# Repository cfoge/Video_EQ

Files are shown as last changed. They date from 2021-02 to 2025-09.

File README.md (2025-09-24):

# Video Equations Video Synthisizer 

This repo is a source for hardware, firmware and programming of the *Video Equations* video synth by CFOGE

[VIDEO OF THE SYNTH IN ACTION](https://youtu.be/mjo5Ck8bLms?si=FF00txjyV0ThEeUl)

## currently for sale on ETSY [here](https://www.etsy.com/au/listing/1103194946/video-equations-video-synthesizer-pcb)
*NOTE IF YOU BUY A KIT OR PCB FROM ME YOU DO NOT NEED TO PROGRAM THE ANYTHING! THE ROM CHIPS COME PROGRAMED!

It also contains the BOM for the original Standalone version.
and a *build guide* [here](https://docs.google.com/document/d/1xhPcSpx6gMqP5NIOa-hU4GBMXX1HIhc-GGcmYRfW-Dc/edit?usp=sharing)

And a mouser basket for the parts [HERE](https://au.mouser.com/ProjectManager/ProjectDetail.aspx?AccessID=cdce1e85b3)  
If any parts are out of stock, check this basket: [HERE](https://au.mouser.com/ProjectManager/ProjectDetail.aspx?AccessID=809015eedc)

When building be sure to look at the interactive BOM (it is the HTML file above)

3D-printed case files can be found here:
[3d printed cases](https://www.thingiverse.com/thing:4983079)

-- To date there have been 100's of these made by all kinds of amazing people and i am flattered to have seen so manny photos and videos of these in use. They are featured in the collections of so many creative people and institutes such as the New York Film School and Princton Media Lab. The Video Equations is also listed on the Wikipedia page for [Video Synthisizers](https://en.wikipedia.org/wiki/Video_synthesizer#cite_note-14)

If you find this useful and would like to pay it forward you can do so [HERE](https://www.paypal.com/donate?hosted_button_id=XGRSY3M6V94R4)

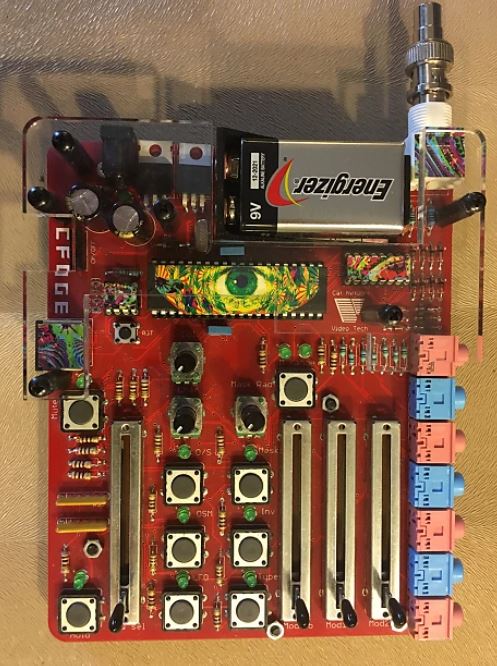
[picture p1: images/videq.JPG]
Red Video Equations


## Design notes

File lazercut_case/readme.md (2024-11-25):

lazer cut case files and pictures of what a Video Equations with a lazer cut case looks like. Instructions linke din the build guide.

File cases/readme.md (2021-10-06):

Cases For the Video Equations as 3d printible STLs

[ALSO ON THINGYVERSE]https://www.thingiverse.com/thing:4983079

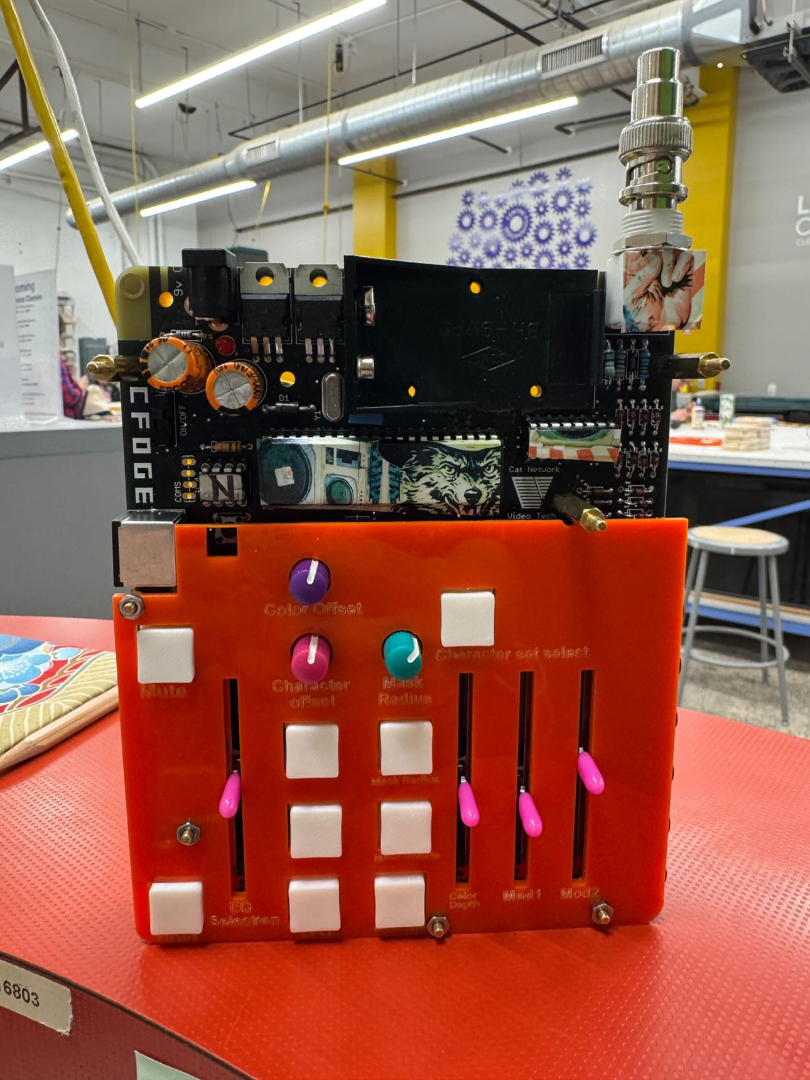
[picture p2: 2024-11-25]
lazercut_case/30529C8E-C561-428F-A3B5-9482B5F51982.JPG

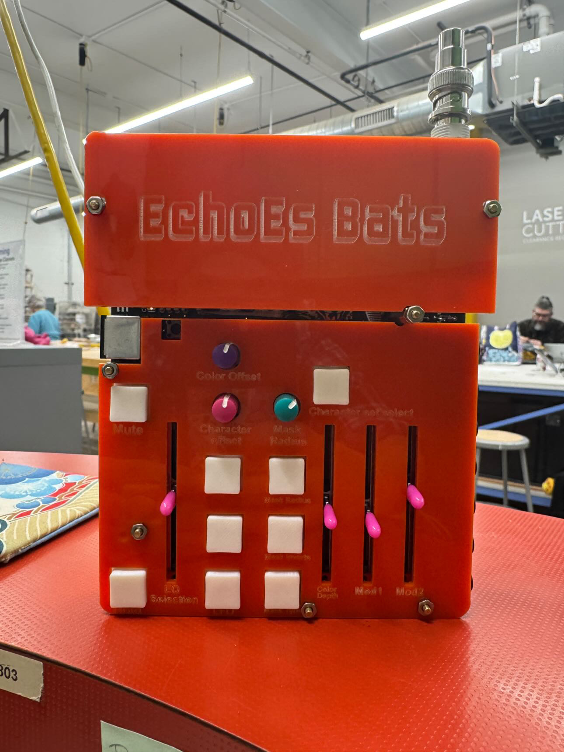
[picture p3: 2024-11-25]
lazercut_case/135A8F83-172F-4E90-950E-6DF78F7B65DF.JPG

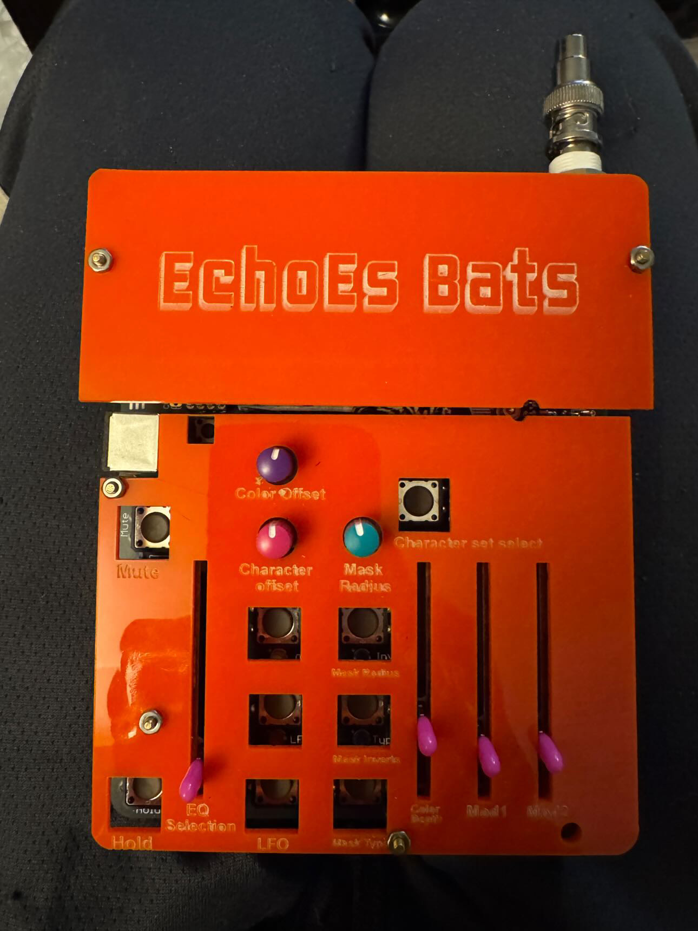
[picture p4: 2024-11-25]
lazercut_case/34D93253-267E-47DA-A76D-7D9487207A3B.JPG

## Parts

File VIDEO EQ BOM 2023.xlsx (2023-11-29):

Customer Reference | VALUE | QTY | NEWARK PART # | PRICE | EXTENDED | DIGIKEY PART # | PRICE | EXTENDED | MOUSER PART # | PRICE | EXTENDED | INFO | ORIGNAL LINK
9v | 2.1mm DC plug (power in is cent -) | 1 | -- |  | $0.00 | EJ508A-ND | $1.28 | $1.28 | -- |  | $0.00 |  | http://www.digikey.com/product-detail/en/mpd-memory-protection-devices/EJ508A/EJ508A-ND/2439547
BAT1 | 9v Battery holder | 1 | -- |  | $0.00 | BH9V-PC-ND | $2.04 | $2.04 | -- |  | $0.00 | Make sure that the positive terminal is on right when looking down with the terminals at the top | http://www.digikey.com/product-detail/en/mpd-memory-protection-devices/BH9VPC/BH9V-PC-ND/31510
C1,C2 | 1000uf Electrolitic Cap | 2 | 74R3415 | $0.00 | $0.00 | P14398-ND | $0.72 | $1.44 | 667-EEU-FM1C102 | $0.00 | $0.00 |  | http://www.digikey.com/product-detail/en/panasonic-electronic-components/EEU-FM1C102/P12366-ND/613727
 | 1000uf Electrolitic Cap (ALT) | 0 | -- |  |  | P12366-ND |  |  | --
C3, C4, C5 | 0.1uf | 3 | 44AC2694 | $0.00 | $0.00 | 495-1149-ND | $0.46 | $1.38 | 871-B32529C1104J | $0.00 | $0.00 |  | http://www.digikey.com/product-detail/en/epcos-tdk/B32529C1104J/495-1147-ND/592724
 | 1000uf Electrolitic Cap(ALT) | 0 | -- |  | $0.00 | 495-1147-ND |  |  | -- |  | $0.00
Coms | 1X4 pinheader | 1 | 63W5458 | $0.00 | $0.00 | 929400E-01-04-ND | $0.47 | $0.47 | 517-929400-01-04-RK | $0.00 | $0.00 |  | http://www.digikey.com/product-detail/en/3m/929400-01-04-RK/929400E-01-04-ND/1093537
D1 | 1n4007 | 1 | 42K2831 | $0.00 | $0.00 | 1N4007GOS-ND | $0.23 | $0.23 | 625-1N4007E-E3/53 | $0.00 | $0.00 | alternate digikey part | http://www.digikey.com/product-detail/en/fairchild-semiconductor/1N4007/1N4007FSCT-ND/965481
D1 (ALT) | 1n4007 | 0 | -- |  | $0.00 | 1N4007FSCT-ND |  |  | -- |  | $0.00 | this digikey part not available
Expand | mini 6pin din | 1 | -- |  | $0.00 | CP-2260-ND | $2.18 | $2.18 | 490-MD-60SM | $0.00 | $0.00 |  | http://www.digikey.com/product-detail/en/cui-inc/MD-60SM/CP-2260-ND/96940
J1-J7 | 3.5mm audio jack (GREEN) | 0 | -- |  | $0.00 | 102-4994-ND | $0.97 | $0.00 | 490-SJ1-3555NG-GR | $0.00 | $0.00 | replacement digikey part | http://www.digikey.com/product-detail/en/cui-inc/SJ1-3555NG/CP1-3555NG-ND/738708
J1-J7 (ALT) | 3.5mm audio jack (BLK OOS) | 0 | -- |  | $0.00 | CP1-3555NG-ND | $0.97 | $0.00 | 490-SJ1-3555NG | $0.00 | $0.00 | digi NON STOCK IN USA | http://www.digikey.com/product-detail/en/cui-inc/SJ1-3555NG-GR/CP1-3555NG-GR-ND/2295996
 | 3.5mm audio jack (BLUE) | 7 | -- |  | $0.00 | 102-4993-ND | $0.97 | $6.79 | 490-SJ1-3555NG-BE | $0.00 | $0.00
R34-R35 | 10K Bussed 6pin | 2 | 62J2820 | $0.00 | $0.00 | 4306R-1-103LF-ND |  | $0.00 | 652-4606X-1LF-10K | $0.00 | $0.00 |  | http://www.digikey.com/product-detail/en/bourns-inc/4606X-101-103LF/4606X-1-103LF-ND/1088960
 |  |  |  |  |  | 4606X-1-103LF-ND
RST | Tactile Switch mom | 1 | 19C7994 | $0.00 | $0.00 | 679-2428-ND | $0.10 | $0.10 | 642-MJTP1230 | $0.00 | $0.00 |  | http://www.digikey.com/product-detail/en/apem-inc/MJTP1230/679-2428-ND/1798037
R1-R3 | 10k pot | 3 | 17M1603 | $0.00 | $0.00 | PTV09A-4020U-B103-ND | $0.83 | $2.49 | 652-PTV09A-4020UB103 (https://www.mouser.com/QuickViewProdDetail.aspx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) | $0.00 | $0.00 | vertical | http://www.digikey.com/product-detail/en/bourns-inc/PTV09A-4020U-B103/PTV09A-4020U-B103-ND/3781130
S1-S9 | 12mm push button mom | 9 | 32AC2270 | out of stock |  | CKN9100-ND | $0.39 | $3.51 | 611-PTS125SM43-LFS | $0.00 | $0.00 |  | http://www.digikey.com/product-detail/en/c-k-components/PTS125SM43-2-LFS/CKN9100-ND/1146743
U1, U3 | 7805 5V req | 1 | 45J1443 | $0.00 | $0.00 | MC7805BTGOS-ND | $0.62 | $0.62 | 926-LM7805CT/NOPB (https://www.mouser.com/QuickViewProdDetail.aspx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) | $0.00 | $0.00 | alternate digikey replacement | http://www.digikey.com/product-detail/en/fairchild-semiconductor/LM7805CT/LM7805CT-ND/458698
U1, U3 (ALT) | 7805 5V req | 0 | -- |  | $0.00 | LM7805CT-ND |  |  | -- |  | $0.00 | TO220 package - out of stock @ digi 3.10.21 (obsolete)
U2 | LM3940 3.3v Reg | 1 | 31AH1990 | $0.00 | $0.00 | LM3940IT-3.3/NOPB-ND | $1.93 | $1.93 | 926-LM3940IT-3.3NOPB (https://www.mouser.com/QuickViewProdDetail.aspx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) | $0.00 | $0.00 | TO220 package | http://www.digikey.com/product-detail/en/texas-instruments/LM3940IT-3.3-NOPB/LM3940IT-3.3-NOPB-ND/308006
Y1 | 5mhz 18pf crystal | 1 | 75Y2315 | $0.00 | $0.00 | 300-6009-ND | $0.54 | $0.54 | 520-50-18-4XEN | $0.00 | $0.00 | possible mouser replacement 5mhf 18pf crystal | http://www.digikey.com/product-detail/en/citizen-finedevice-co-ltd/HC-49-U-S5000000ABJB/300-6009-ND/284197
Y1-A | 5mhz 18pf crystal | 0 | -- |  |  | -- |  |  | 695-HC49US-5-U | $0.00 |  | very long lead for this part from mouser
D2-D15 | 5v zener diode | 14 | 90R9455 | $0.00 | $0.00 | 1N5231B-ND | $0.15 | $2.07 | 512-1N5231B | $0.00 | $0.00 |  | ZENER (http://www.newark.com/nxp/bzx79-c5v1-113/zener-diode-500mw-5-1v-do-35/dp/75R5151) | ZENER AL (https://www.newark.com/multicomp-pro/1n5231b/zener-diode-500mw-5-1v-do-35/dp/90R9455)
SCK - X1 | 16p DIL (DIP) sockt | 1 | 82K7788 | $0.00 | $0.00 | 609-4713-ND | $0.37 | $0.37 | 649-DILB16P-223TLF | $0.00 | $0.00 |  | DIP8 (http://www.newark.com/amphenol-fci/dilb8p-223tlf/dip-socket-8-position-2-54mm-through/dp/53K0893)
SCK - U$2 | 40p DIL (DIP) sockt | 1 | 53K0892 | $0.00 | $0.00 | 609-4716-ND | $0.76 | $0.76 | 649-DILB40P223TLF | $0.00 | $0.00 |  | DIP40 (http://www.newark.com/amphenol-fci/dilb40p-223tlf/dip-socket-40-position-through/dp/53K0892)
SCK - IC1 | 8pin DIL (DIP) socket | 1 | 53K0893 | $0.00 | $0.00 | 609-4717-ND | $0.20 | $0.20 | 649-DILB8P223TLF | $0.00 | $0.00 |  | DIP16 (http://www.newark.com/multicomp/spc15498/dip-socket-16-position-through/dp/82K7788)
VR1-VR4 | 10k slide pot | 4 | 05R8045 | $0.00 | $0.00 | PTA4543-2015DPB103-ND | $1.50 | $6.00 | 652-PTA45432015DPB10 | $0.00 | $0.00 | Timeslide60 | TIMESLIDE60 (http://www.newark.com/bourns/pta4543-2015dpb103/potentiometer-slide-10kohm-250mw/dp/05R8045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)
U$1 | BNC Conector | 1 | 98K4758 | $0.00 | $0.00 | A97552-ND | $2.42 | $2.42 | 571-1-1337542-0 | $0.00 | $0.00 |  | BNC (http://www.newark.com/te-connectivity-greenpar/1-1337542-0/rf-coaxial-bnc-jack-r-a-50-ohm/dp/78M7204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)
LED 1-LED11 | 3mm LED - GREEN | 8 | 97K4040 | $0.00 | $0.00 | 160-1712-ND | $0.36 | $2.88 | 859-LTL-4231 | $0.00 | $0.12 | I use red for the 3 most left led's , red and green will look nice orenge is often too bright. | GREEN (http://www.newark.com/led-technology/l02r3000f1/led-green-t-1-3mm-3-7mcd-567nm/dp/97K4040?ost=1208845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) | RED (http://www.newark.com/led-technology/l4rr3000f1/led-red-t-1-3mm-4-3mcd-635nm/dp/97K4135?ost=1208848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)
LED 1-LED11 | 3mm LED - RED | 3 | 97K4135 | $0.00 | $0.00 | 160-1955-ND | $0.36 | $1.08 | 859-LTL-4211 | $0.00 | $0.00
LED 1-LED11 | 3mm LED - YELLOW | 0 | 97K4047 |  | $0.00 | 160-1961-ND | $0.36 | $0.00 | 859-LTL-4251 | $0.00 | $0.00
LED 1-LED11 | 3mm LED - ORANGE | 0 | 14N9382 |  | $0.00 |  |  |  | 859-LTL-1CHAE | $0.00 | $0.00
on/Off | Slide Switch | 1 | EG1218 |  | $0.00 | EG1903-ND | $0.66 | $0.66 | 612-EG1218 | $0.00 | $0.00 | Switch | SLIDE (http://www.newark.com/e-switch/eg1218/slide-switch-spdt-200ma/dp/15N7301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)
R1-R20 | 100ohm res 1/4w CF | 20 | 38K0326 |  | $0.00 | 100QBK-ND | $0.10 | $2.00 | 603-CFR-25JB-52-100R | $0.00 | $0.00 |  | 100-ohm (http://www.newark.com/multicomp/mcf-0-25w-100r/carbon-film-resistor-100-ohm-250mw/dp/38K0326)
R21 | 1k res 1/4w CC | 1 | 25M8365 |  | $0.00 | RC14JT1K00CT-ND | $0.54 | $0.54 | 791-RC1/4-102JB | $0.00 | $0.00 | sub'd - | 1k 250mw (https://www.newark.com/multicomp-pro/mcf-0-25w-1k/carbon-film-resistor-1kohm-250mw/dp/38K0327?ost=38k0327)
R21 (ALT) | 1k res 1/4w CC | 0 | 72K6178 |  | $0.00 | -- |  |  |  |  |  | -2 dllars and back ordered | 1k (http://www.newark.com/multicomp/mcrc1-4g102jt-rh/carbon-resistor-1kohm-250mw-5/dp/72K6178?ost=1144061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)
R26-R29 & R36-R38 | 47ohm 1/4w CF | 7 | 38K0374 |  | $0.00 | 47QBK-ND | $0.10 | $0.70 | 603-CFR-25JB-52-47R | $0.00 | $0.00 |  | 47-ohm (http://www.newark.com/multicomp/mcf-0-25w-47r/carbon-film-resistor-47-ohm-250mw/dp/38K0374?ost=9339523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)
R30 | 1.1k 1/4w MF | 1 | 59K8658 |  | $0.00 | CMF1.10KQFCT-ND | $0.61 | $0.61 | 71-CMF501K1000FHEB | $0.00 | $0.00 |  | 1.1k (http://www.newark.com/multicomp/mcmf0w4ff1101a50/metal-film-resistor-1-1kohm-250mw/dp/59K8658)
R31 | 270ohm 1/4w MF | 1 | 58K3836 |  | $0.00 | 270ADCT-ND | $0.70 | $0.70 | 603-MFP-25BRD52-270R | $0.00 | $0.00 |  | 270ohm (http://www.newark.com/multicomp/mcmf0w4ff2700a50/metal-film-resistor-270-ohm-250mw/dp/58K3836)
R32 | 500ohm 1/4w MF | 1 | 97M6276 |  | $0.00 | RN60C5000BB14-ND | $0.73 | $0.73 | 71-RN60C5000B | $0.00 | $0.00 |  | 500ohm (http://www.newark.com/multicomp/mcmfr0w4bb5000a50/metal-film-resistor-500-ohm-250mw/dp/97M6276?ost=2396013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)
R33 | 10K 1/4w CC | 1 | 72K6179 |  | $0.00 | RC14JT10K0CT-ND | $0.54 | $0.54 | 791-RC1/4-103JB | $0.00 | $0.00 |  | 10k (http://www.newark.com/multicomp/mcrc1-4g103jt-rh/carbon-resistor-10kohm-250mw-5/dp/72K6179?ost=1133371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)
IC1 | Eprom 24LC256 | 1 |  |  |  |  |  |  |  |  |  | firmware chip, comes with pcb order
U$2 | Paralax P8X32A-D40 | 1 | 11X5686 |  | $7.99 | P8X32A-D40-ND | $9.19 | $9.19 | 619-P8X32A-D40 | $7.99 | $7.99 | Propellor IC | EPROM (https://www.parallax.com/product/602-00013)
X1 | MPC3208 | 1 | 58K1815 |  | $4.40 | MCP3208-CI/P-ND | $3.83 | $3.83 | 579-MCP3208CIP | $3.83 | $3.83 | 8ch ADC | PROPELLER (https://www.parallax.com/product/p8x32a-d40)
 |  |  |  |  |  |  |  |  |  |  | $0.00
 |  |  |  |  |  |  |  |  |  |  | $0.00 |  | ADC (http://www.mouser.com/ProductDetail/Microchip-Technology/MCP3208-CI-P/?qs=9y3LFqDLL8IuAGJEebQX9g%3d%3d)
 |  |  | TOTAL NEWARK |  | $12.39 | TOTAL DIGI |  | $60.28 | TOTAL MOUSER |  | $11.94

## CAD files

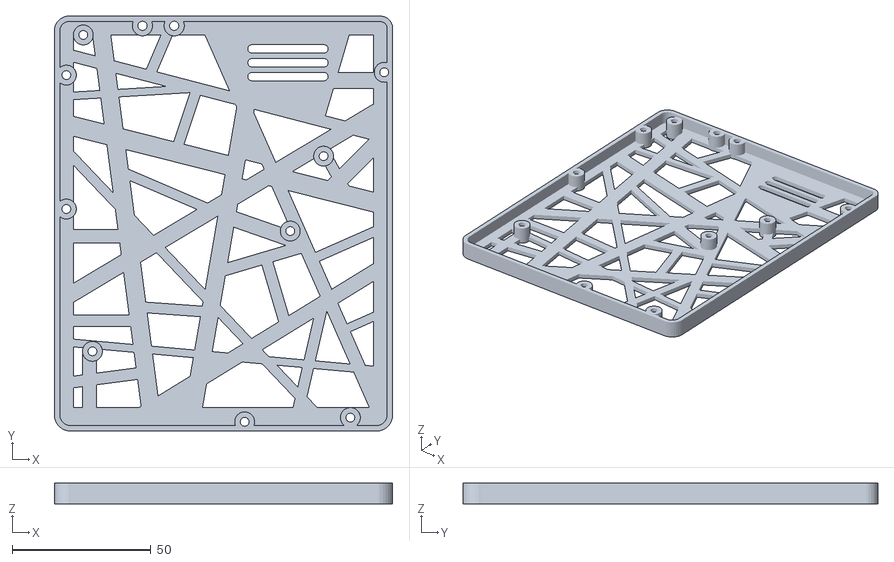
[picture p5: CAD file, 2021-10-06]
cases/VIDEQ SKELL.stl
122.0 x 149.6 x 7.50

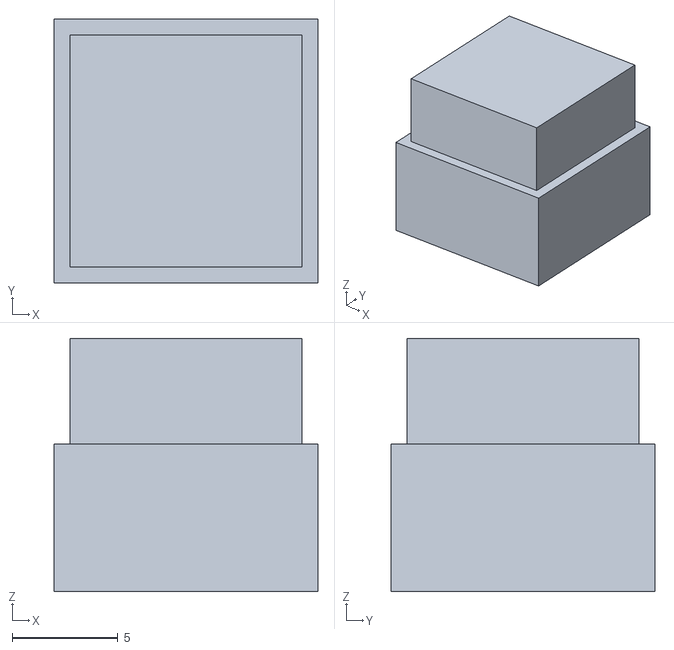
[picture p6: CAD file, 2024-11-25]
lazercut_case/Buttons for Video Equations 003.stl
12.5 x 12.5 x 12.0

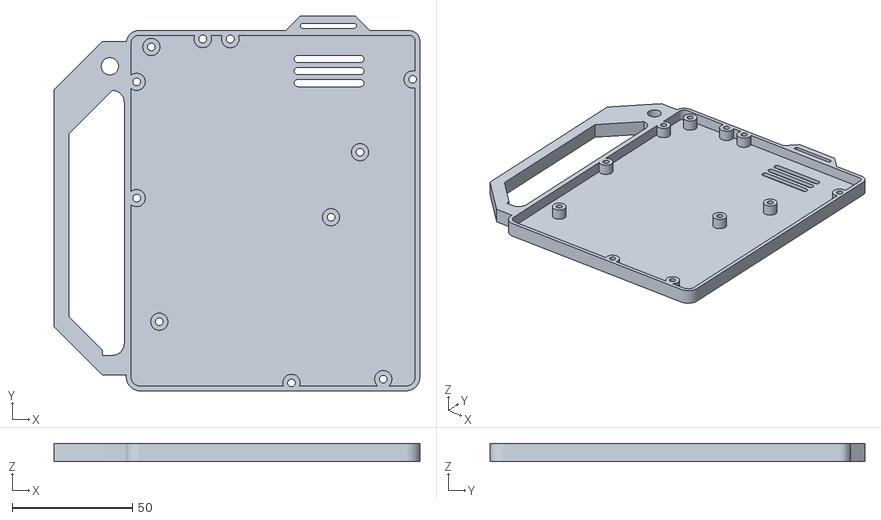
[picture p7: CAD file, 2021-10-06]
cases/VID EQ COMPLEX CASE.stl
151.9 x 155.5 x 7.50

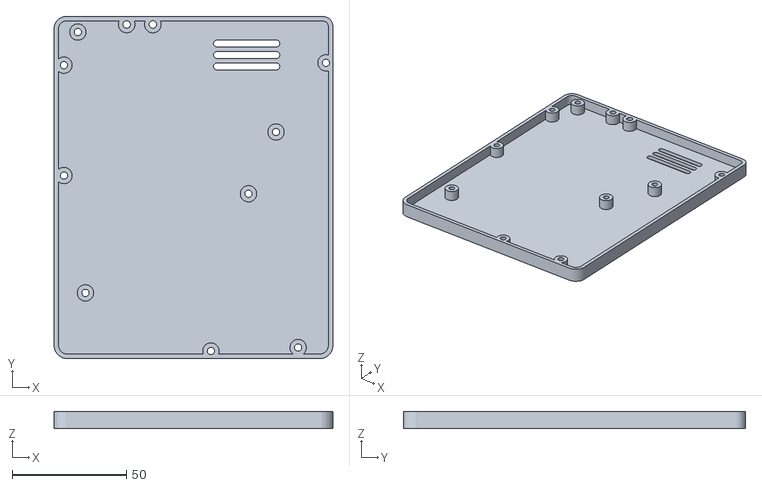
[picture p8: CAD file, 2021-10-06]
cases/VID EQ SIMPLE CASE.stl
122.0 x 149.6 x 7.50

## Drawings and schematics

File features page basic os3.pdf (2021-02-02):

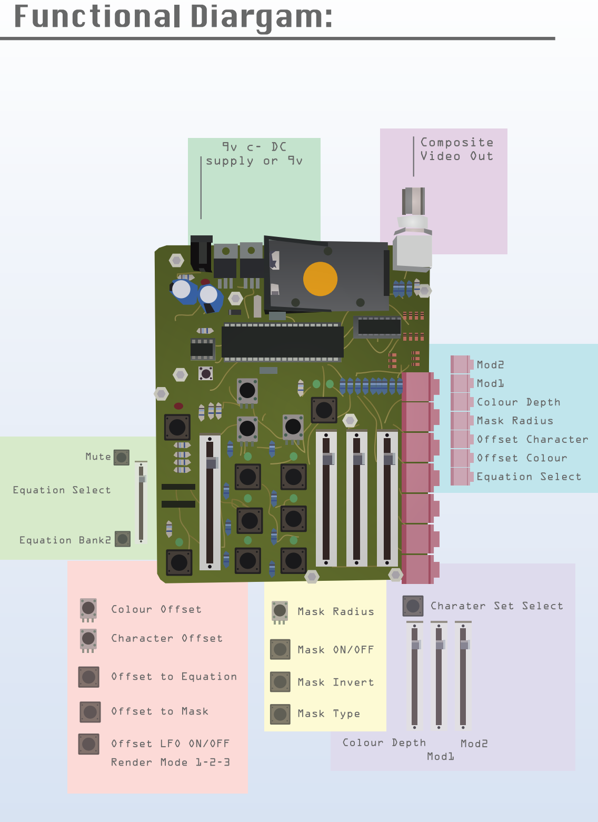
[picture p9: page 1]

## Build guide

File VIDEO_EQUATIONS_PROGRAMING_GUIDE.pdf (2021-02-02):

## VIDEO EQUATIONS PROGRAMING GUIDE:

30/01/2018 Rd Jordan / Cat Full of Ghosts Electronics

This guide will take you through how to load alternative operating systems on the VIDEO EQUATIONS.

A little bit about how the Video Equations (VE) handles its firmware. The VE uses a Parallax Propeller as its main brain. When you start up the VE the Propeller reaches out via i2c to a small 8 pin eeprom which contains the firmware (or program) that the VE runs. By swapping out the eeprom or by reprograming it you can load new software onto the VE. Because I still use the VE to VJ I am slowly working on new firmware/programs for it. This guide will help you load these new programs onto your device to use/test and also return to your original OS/firmware.

WHAT YOU WILL NEED:

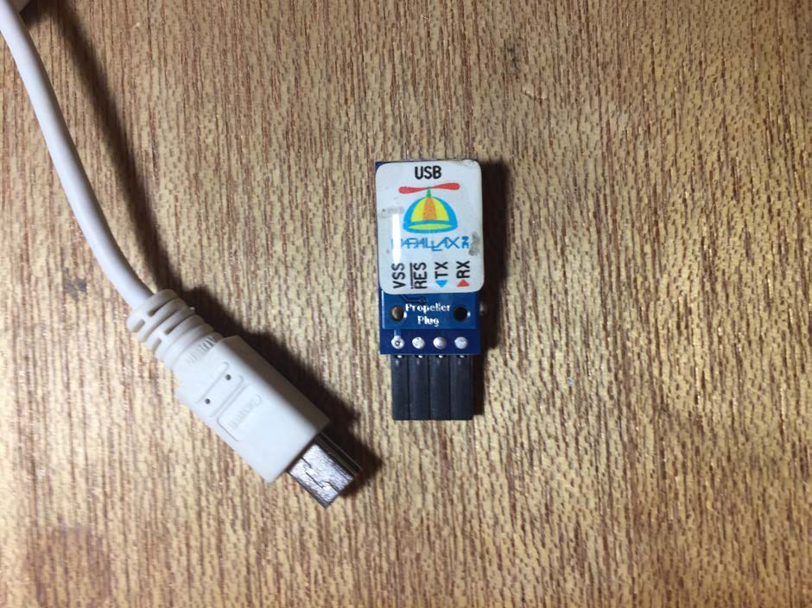
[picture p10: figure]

A prop programmer, https://www.parallax.com/product/32201
There are other devices that can program a Parallax Propeller, but the simplest method is using a USB Prop Plug.

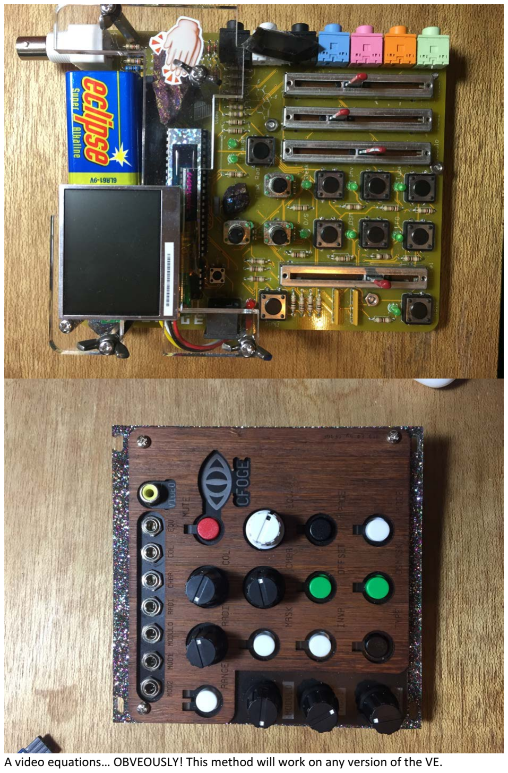
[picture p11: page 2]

A video equations… OBVEOUSLY! This method will work on any version of the VE.

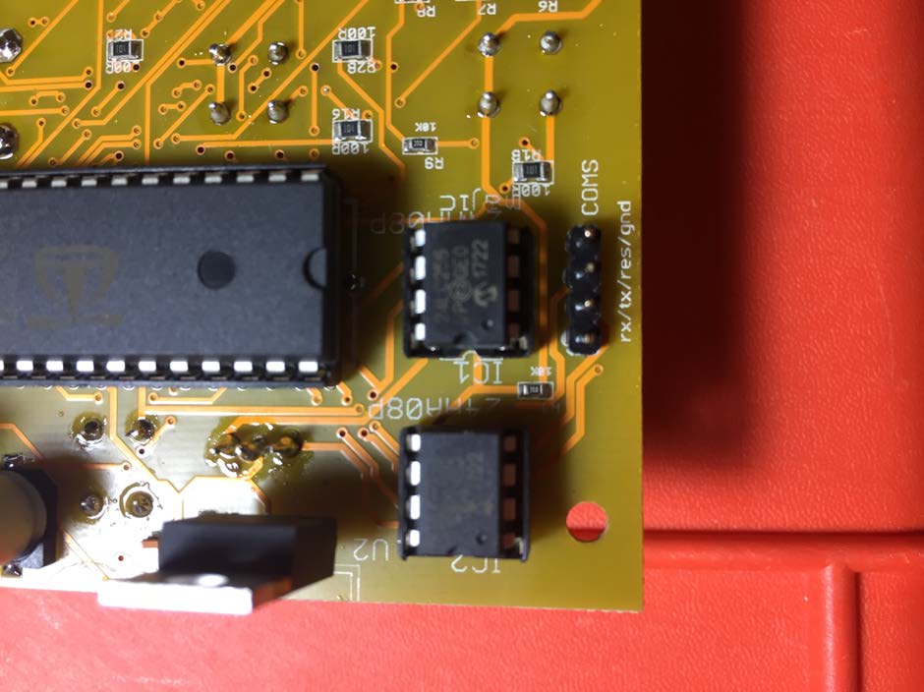
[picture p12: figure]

STEP1:

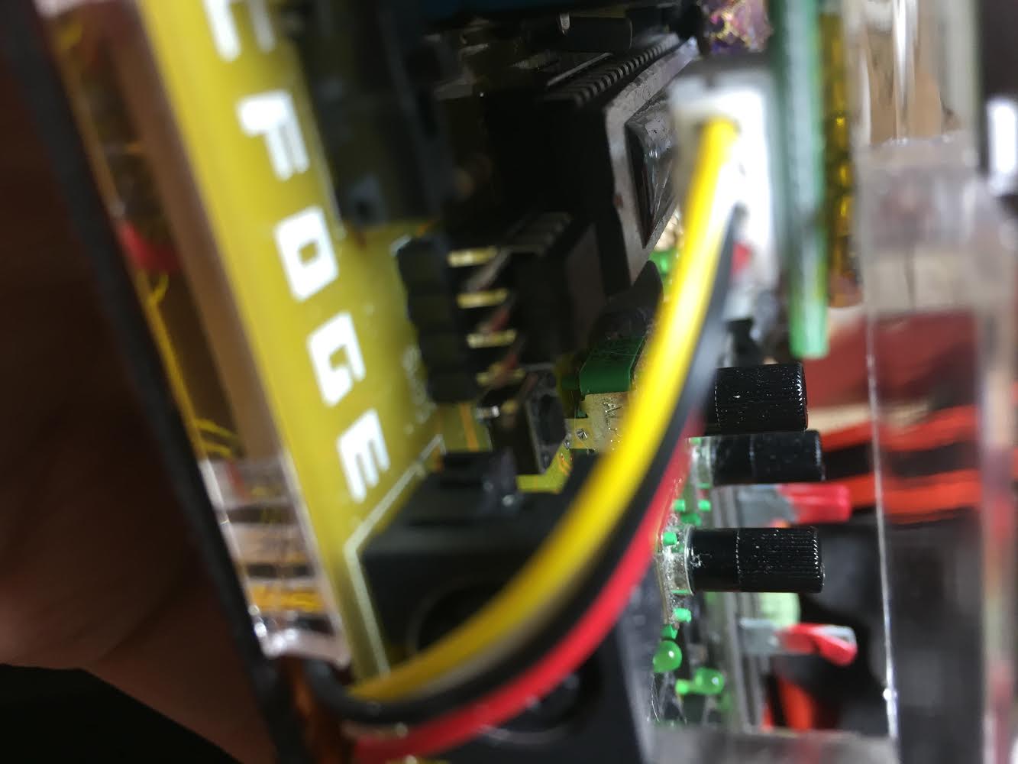
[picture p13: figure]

Locate the programing header on your device, there will be 4 pins, they may be unlabelled if you have an early version of the VE.

STEP2:
PLUG IN THE PROP PLUG CORRECTLY!

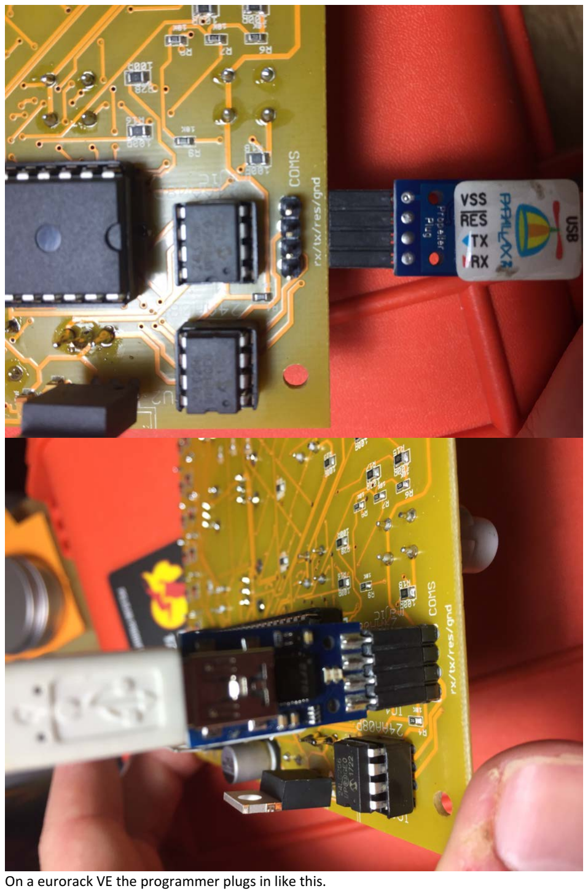
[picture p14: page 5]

On a eurorack VE the programmer plugs in like this.

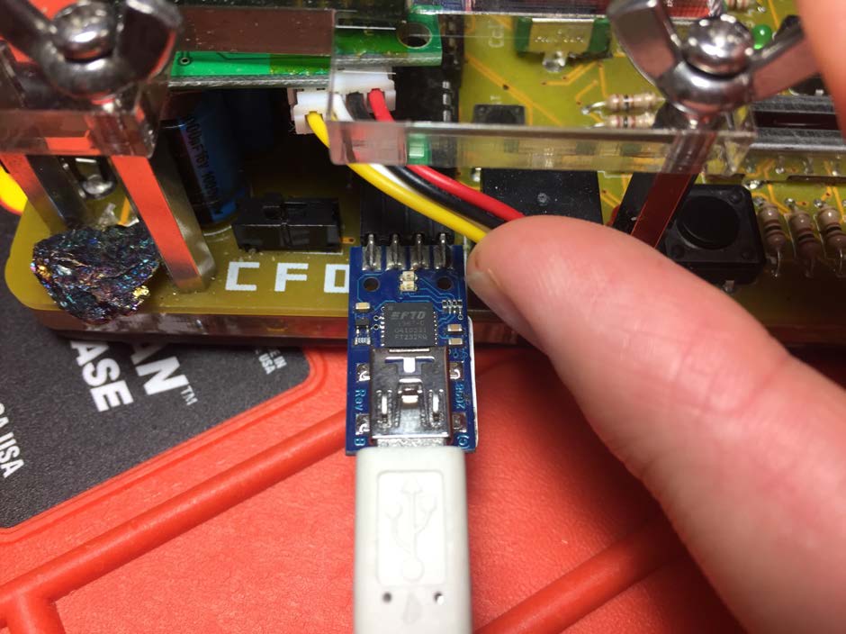
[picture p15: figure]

on a standalone it plugs in like this, with the vss/gnd pin facing the power jack.

IF YOU HAVE DONE THIS CORRECTLY THE POWER LED WILL DIMLY ILUMINATE WHEN THE PROP PLUG PROGRAMER IS PLUGED INTO YOUR USB. IF THIS DOESN’T HAPPEN CHECK YOU HAVE THE PLUG THE RIGHT WAY AROUND.

STEP3:
Download the IDE for the Propellor:
MAC >> https://www.parallax.com/downloads/propelleride-software-mac-spin-pasmpropbasic
PC >> https://www.parallax.com/downloads/propeller-tool-software-windows-spinassembly
LINUX >> https://www.parallax.com/downloads/propelleride-software-linux-spin-pasmpropbasic

STEP4:
Download the firmware/programs you wish to upload. www.catfullofghosts.com/veprog
Here are some programs, they may not be the latest based on then you are reading this.

STEP5:
Open the .spin file with a XXX at the start in your IDE any file with an XXX at the start is a program, the other files are support files.

STEP6:
Power up you VE, your VE needs to be on to program. The power LED should change from dim to bright.

Step7:

All three of these icons will change from dimed to bright and you will be able to click on them. If you are unable to you may not have the programmer plugged in correctly, the Video Equations may not be powered on, or your computer may not have recognised the programmer. The first two issues are covered above, for the third, try unplugging and replunging, using a different usb port.

The arrow right button will load the program into volatile ram >> That means it will put the program on your VE but it will not remain after you power the unit off.

The arrow down button will load the program into EEprom >> this means that the program will remain after power is removed.

Step8:
YOU ARE DONE!!!

New beta software can be unstable and crash the machine, or may seem sluggish in places, its experimental and should be treated as such.

## If this guide at all helped you and you want to say thanks, I have a PayPal donation button here:

## http://www.catfullofghosts.com/donate

## Donations help to keep updates free for everyone and also help to

fund new projects.

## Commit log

2021-02-02 Add files via upload
    resources
    [VIDEO EQ BOM WITH LINKS.xlsx]
2021-03-10 Add files via upload
    correct BOMS for standalone, not euro.
    [VIDEO EQ BOMv2 AUS.xlsx, VIDEO EQ BOMv2 USA.xlsx]
2021-05-25 Add files via upload
    new better bom
    [CFOGE_BOMS_COMBINED_V1dot0.xlsx]
2021-06-16 Add files via upload
    clarified power input as cent -
    fixed error in number of resistors
    [CFOGE_BOMS_COMBINED_V1dot0.xlsx, VIDEO EQ BOMv2 AUS.xlsx, VIDEO EQ BOMv2 USA.xlsx]
2022-09-14 Add files via upload
    Old boms, moved to this folder
    [CFOGE_BOMS_COMBINED_V1dot0.xlsx, VIDEO EQ BOMv2 AUS (7).xlsx, VIDEO EQ BOMv2 USA (2).xlsx]
2023-11-29 bom fixed
    [CFOGE_BOMS_COMBINED_V1dot0.xlsx, VIDEO EQ BOM 2023.xlsx, VIDEO EQ BOMv2 AUS (7).xlsx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]
2024-06-09 Add files via upload
    interactive bom added
2024-11-25 Add files via upload
    need to fix up the file and remove the echo bats part
    [Buttons for Video Equations 003.stl]
2024-11-25 Add files via upload
    more photos of the case
